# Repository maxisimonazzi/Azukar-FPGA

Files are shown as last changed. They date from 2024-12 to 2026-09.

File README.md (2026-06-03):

<div align="center">
  <h1>AZUKAR Logo  AZUKAR — FPGA Education Board</h1>
  <h1>UTN-FRT - Ingeniería Electrónica</h1>
</div>

[English](#english) | [Español](#español)









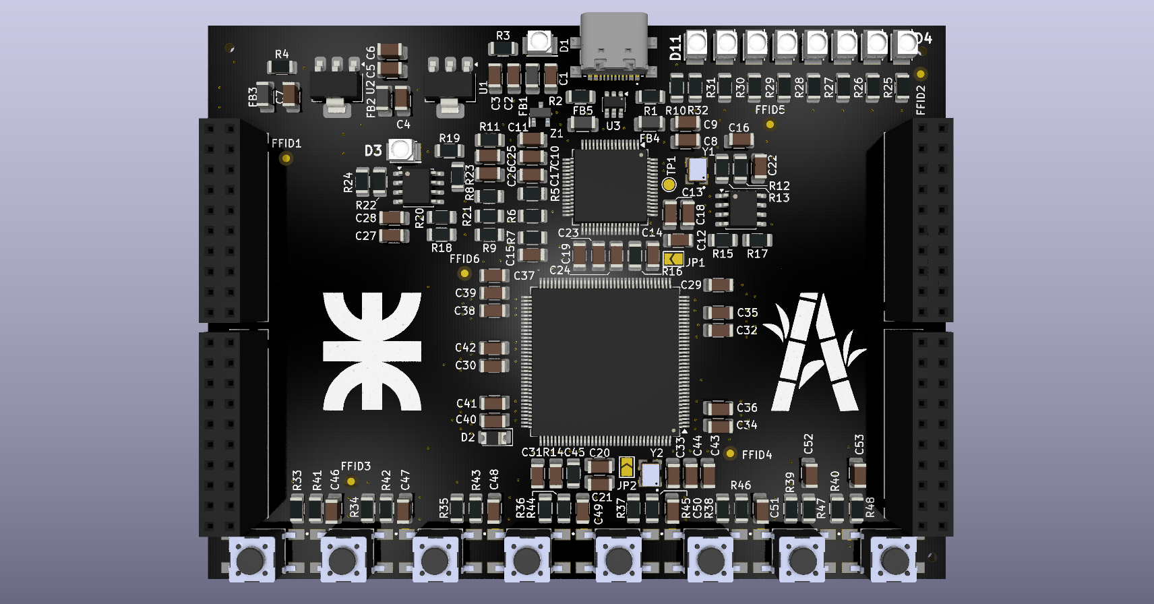
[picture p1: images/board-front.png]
Front Preview

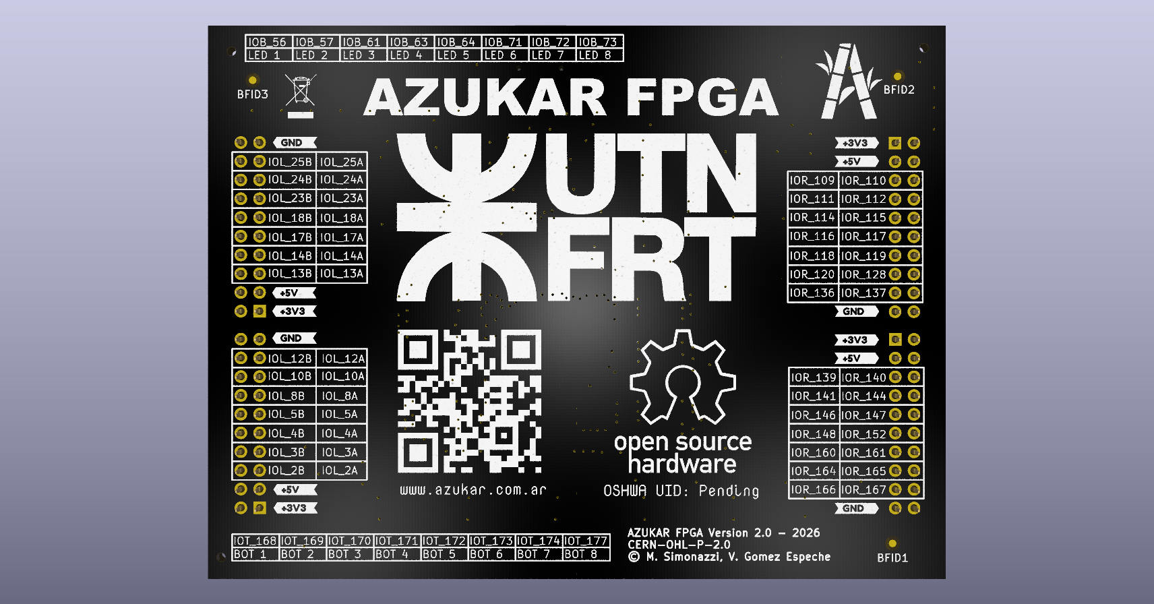
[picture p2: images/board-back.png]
Back Preview


# English

## Overview

**AZUKAR** is an open-source FPGA development board designed for digital design education, laboratory training, and rapid prototyping.
It provides an accessible and reproducible hardware platform that enables students, makers, and engineers to explore HDL design, digital systems architecture, and FPGA-based applications using open toolchains.

The project follows open hardware principles and is optimized for academic environments, hands-on learning, and experimentation.

### Special Considerations

Assembly-first decisions were made to keep the board easy to build in a lab or at home: most parts use common, hand-solderable footprints (e.g., 1206, SOT-233-3, SOIC-8, 3528, SOT-23-6), and all components are placed on the TOP side of the PCB to simplify manual assembly and hot-plate reflow. The only parts that typically require extra precision or a different soldering technique are the FPGA (TQFP-144), the FTDI USB interface (LQFP-64), and the 3225 package crystals. As a trade-off, these assembly-friendly decisions make the routing denser and therefore increase via usage compared to a design that spreads parts across both PCB sides.

## Key Goals

The main idea behind AZUKAR is to make FPGA learning feel approachable and practical, especially in the context of digital design courses and hands-on training. To do that, the board is designed to work well with open-source FPGA toolchains and to keep the hardware design easy to understand, reproduce, and verify.

At the same time, this is meant to be a solid platform for lab work and academic use, not just a one-off prototype. The project is open to contributions and experiments from the community, so people can build on it, adapt it to their needs, and share improvements back.

## Features

AZUKAR is an FPGA-based digital logic platform with fully open hardware design files, created and maintained in KiCad 9. It is intended to work smoothly with open-source synthesis and programming workflows, so the learning experience doesn’t depend on proprietary tools.

From the start, the board is designed with education in mind: the I/O and peripherals are chosen to support typical lab exercises and digital design practice. The overall architecture is modular and extensible, so it can grow with new experiments, add-ons, and future improvements.

## Repository Structure

/docs -> Documentation of the board, pinout, datasheets, etc

/images -> Images

/project -> Kicad project

## Toolchain Compatibility

AZUKAR is designed to fit naturally into open-source FPGA workflows. In practice, that means you can synthesize designs with tools like Yosys, run place-and-route with NextPNR, and program the board using open programming utilities. The goal is to keep the HDL flow as vendor-independent as possible, so the same learning and development approach can be reused across projects.

## Educational Use

This board is intended to be used in real learning environments: university courses, digital electronics labs, and introductory FPGA workshops. It also works well for self-learning and experimentation at home, and it can serve as a practical base for small research prototypes where having an open, reproducible platform is a plus.

## Open Hardware

AZUKAR follows open hardware principles:

- Schematics and PCB files available
- Reproducible fabrication workflow
- Community-driven development

License details are available in the repository.

## Contributing

Contributions are welcome:

- Hardware improvements
- Documentation updates
- Example designs
- Testing and validation
- Educational material

Please open issues or pull requests.

## License

This project is released under an open-source hardware compatible license.  
See the LICENSE file for details.

## Attribution

If you use this project as a reference or as a base for derivative works, the CERN-OHL-P license requires preservation of attribution to the original AZUKAR project.

We strongly encourage including in documentation and repositories:
- A reference to this repository (link and name)
- The original author name
- The license notice

This helps maintain traceability and academic integrity within the open hardware community.

## Disclaimer

This project is an independent hardware design based on publicly available documentation of the Lattice iCE40HX FPGA family.
It is not affiliated with, endorsed by, or supported by Lattice Semiconductor.

---

# Español

## Descripción general

**AZUKAR** es una placa de desarrollo FPGA de código abierto diseñada para la educación en diseño digital, la capacitación de laboratorio y el prototipado rápido.
Proporciona una plataforma de hardware accesible y reproducible que permite a estudiantes, makers e ingenieros explorar el diseño en HDL, la arquitectura de sistemas digitales y aplicaciones basadas en FPGA usando toolchains abiertas.

El proyecto sigue principios de hardware abierto y está optimizado para entornos académicos, aprendizaje práctico y experimentación.

### Consideraciones especiales

Se tomaron decisiones orientadas al montaje para que la placa sea más fácil de construir en laboratorio o en casa: la mayoría de los componentes usan encapsulados comunes y soldables a mano (por ejemplo 1206, SOT-233-3, SOIC-8, 3528, SOT-23-6), y todos los componentes están ubicados en la cara TOP de la PCB para facilitar el armado manual y el soldado por reflow con cama caliente. Los únicos componentes que suelen requerir más precisión o una técnica de soldado diferente son la FPGA (TQFP-144), la interfaz FTDI del puerto USB (LQFP-64) y los cristales en encapsulado 3225. Como contrapartida, estas decisiones orientadas al ensamblado vuelven el ruteo más complejo y, por lo tanto, aumentan la cantidad de vías respecto de un diseño que distribuye componentes en ambas caras de la PCB.

## Objetivos principales

La idea principal de AZUKAR es que aprender FPGA sea más accesible y práctico, especialmente para materias de diseño digital y actividades de laboratorio. Por eso se buscó que la placa pueda trabajar con toolchains de FPGA de código abierto y que el diseño de hardware sea transparente, entendible y fácil de reproducir.

Además, el objetivo es que sirva como una plataforma sólida para uso académico y entrenamiento, no sólo como un prototipo aislado. El proyecto también está pensado para que la comunidad pueda aportar, probar ideas y experimentar, de forma que cualquiera pueda adaptarlo y mejorar lo que ya existe.

## Características

AZUKAR es una plataforma de lógica digital basada en FPGA, con archivos de diseño de hardware totalmente abiertos y desarrollados en KiCad 9. La placa está pensada para integrarse bien con herramientas de síntesis y programación de código abierto, para que el flujo de trabajo sea accesible y fácil de replicar.

También se priorizó el uso educativo: las entradas/salidas y los periféricos apuntan a cubrir prácticas típicas de laboratorio y ejercicios de diseño digital. La arquitectura, además, es modular y extensible, lo que permite sumar ideas, módulos y mejoras con el tiempo.

## Estructura del repositorio

/docs -> Documentación de la placa, pinout, hojas de datos, etc.

/images -> Imágenes

/project -> Proyecto de KiCad

## Compatibilidad con toolchains

AZUKAR está pensada para integrarse de forma natural con flujos de trabajo de FPGA de código abierto. En la práctica, esto incluye poder sintetizar con herramientas como Yosys, hacer place & route con NextPNR y programar la placa con utilidades abiertas. La idea es mantener el flujo de HDL lo más independiente posible del proveedor, para que lo aprendido sea reutilizable y fácil de replicar.

## Uso educativo

Esta placa está pensada para usarse en entornos reales de aprendizaje: cursos universitarios, laboratorios de electrónica digital y talleres introductorios de FPGA. También es muy útil para el autoaprendizaje y la experimentación, y puede servir como base para prototipos de investigación donde suma contar con una plataforma abierta y reproducible.

## Hardware abierto

AZUKAR sigue principios de hardware abierto:

- Esquemáticos y archivos de PCB disponibles
- Flujo de fabricación reproducible
- Desarrollo impulsado por la comunidad

Los detalles de la licencia están disponibles en el repositorio.

## Contribuciones

Las contribuciones son bienvenidas:

- Mejoras de hardware
- Actualizaciones de documentación
- Diseños de ejemplo
- Pruebas y validación
- Material educativo

Por favor, abrir issues o pull requests.

## Licencia

Este proyecto se publica bajo una licencia compatible con hardware abierto y de código abierto.  
Ver el archivo LICENSE para más detalles.

## Atribución

Si utilizás este proyecto como referencia o como base para obras derivadas, la licencia CERN-OHL-P exige que se preserve la atribución al proyecto original AZUKAR.

Se recomienda especialmente incluir en la documentación y repositorios:
- Una referencia a este repositorio (enlace y nombre)
- El nombre del autor original
- El aviso de licencia

Esto ayuda a mantener la trazabilidad y la integridad académica dentro de la comunidad de hardware abierto.

## Descargo de responsabilidad

Este proyecto es un diseño de hardware independiente basado en documentación de acceso público de la familia de FPGA Lattice iCE40HX.
No está afiliado a, avalado por, ni respaldado por Lattice Semiconductor.

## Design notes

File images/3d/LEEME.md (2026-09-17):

# Azukar FPGA — modelo para web

Modelo de presentación generado a partir del proyecto KiCad suministrado. Se mantienen los cuatro conectores laterales, el USB, los pulsadores y los componentes del proyecto. No se modificó el ZIP original.

## Qué archivo usar

- **azukar-web.glb**: 2.178.696 bytes (2,18 MB). Primera opción para reemplazar el modelo en un visor moderno. Texturas incluidas, sin decodificador de geometría adicional. El visor debe soportar KHR_mesh_quantization y EXT_texture_webp.
- **azukar-web-meshopt.glb**: 1.314.468 bytes (1,31 MB). Misma geometría y materiales, comprimidos con Meshopt. Requiere soporte de EXT_meshopt_compression; el decodificador clásico y su licencia están en vendor/.
- **azukar-poster.webp**: 91.058 bytes (91 KB), fondo transparente. Imagen inicial recomendada para la página.
- **azukar-front.webp / azukar-back.webp**: vistas de frente y dorso, de unos 110 y 95 KB.
- **azukar-hero.png / azukar-front.png / azukar-back.png**: renders PNG transparentes de mayor calidad.
- **azukar-editable.blend**: escena editable de Blender 5.0.1 con texturas empaquetadas, cámara e iluminación. No necesitás Blender para mostrar los GLB en la web.

Las dimensiones del PCB se mantienen en 100 × 75 × 1,6 mm. glTF utiliza metros. La cara de componentes apunta hacia +Y en el GLB. La escena Blender conserva la cara de componentes hacia +Z.

## Qué se optimizó

La exportación completa de referencia del mismo proyecto, con pistas, pads, zonas, máscara y serigrafía como geometría, medía 23.832.564 bytes. Contenía 463.670 triángulos y 29.004 primitivas. No es una medición del antiguo archivo del sitio.

Los dos GLB finales tienen 59.827 triángulos y 20 primitivas: aproximadamente 87 % menos triángulos y 99,93 % menos primitivas. Las primitivas son lotes de geometría/material, no una medición literal de todas las llamadas de dibujo del navegador: sombras y otras pasadas pueden sumar llamadas.

- Las 200 vías pequeñas se representan mediante textura/relieve superficial, sin cilindros ni perforaciones internas.
- Se conservan las 85 perforaciones de las huellas; se simplifica su contorno.
- Pistas, máscara, pads, logos y serigrafía se obtienen de las capas reales del PCB, no de una imagen inventada.
- Se simplifican los componentes y se agrupa la geometría por material.
- Se añaden materiales de plástico, cerámica y metal. El color, la rugosidad y el relieve son una aproximación visual basada en las referencias; no una medición física.
- El color de cada cara se guarda a 2048 × 1536; los mapas de relieve y propiedades del material, a 1024 × 768. Se comprimen en WebP.

No es un modelo para fabricación, análisis mecánico preciso o inspección de vías internas. No se inventaron marcas láser ni textos de los chips ausentes en los modelos fuente. La apariencia final también depende de la iluminación y exposición del visor.

## Cómo evitar que frene la página

La compresión del archivo por sí sola no elimina el coste de cargar el motor 3D, preparar materiales y subir datos a la GPU.

1. Mostrar azukar-poster.webp como imagen normal al abrir la página.
2. Cargar el código del visor y asignar el GLB solamente al pulsar «Explorar en 3D».
3. Mantener la imagen mientras se prepara el modelo; conservarla también si WebGL o la carga fallan.
4. No precargar el GLB ni importar el motor 3D desde el módulo inicial.
5. Evitar el giro automático permanente. En visores propios, renderizar cuando cambia la vista; limitar la resolución en pantallas de alta densidad.

El botón de activación protege la carga inicial. Al activar el 3D todavía puede haber trabajo en el hilo principal: no es una garantía de cero pausas en todos los dispositivos. La descarga asíncrona, un setTimeout o requestIdleCallback por sí solos no llevan todo el render a un worker.

Para model-viewer 4.3.1, cargar la biblioteca con import() dentro del manejador del botón y crear el elemento después. Si se usa la variante Meshopt, antes de crear el elemento:

```js
customElements.get('model-viewer').meshoptDecoderLocation =
  '/ruta-a-los-assets/vendor/meshopt_decoder.js';
```

Esa propiedad requiere el script clásico incluido, no meshopt_decoder.module.js. Para un visor Three.js propio, configurar GLTFLoader.setMeshoptDecoder() con el módulo MeshoptDecoder correspondiente. Con azukar-web.glb no hace falta esta configuración.

Referencias oficiales: [carga en model-viewer](https://modelviewer.dev/examples/loading/), [API de model-viewer](https://modelviewer.dev/docs/index.html), [gltfpack](https://github.com/zeux/meshoptimizer/blob/v1.2/gltf/README.md).

## Verificación y alcance

Los GLB cargaron sin errores JavaScript en Edge/Chromium con model-viewer 4.3.1. Se revisaron las vistas de frente, dorso y perspectiva. La prueba local comprobó que no se solicita el GLB ni la biblioteca del visor antes de pulsar el botón.

El validador glTF no encontró errores ni advertencias. Para Meshopt, el validador declara que no inspecciona internamente la extensión comprimida; su carga se comprobó además en el navegador. Las pruebas funcionales con CPU limitada a 4× no sustituyen una medición en teléfonos reales y con la red del sitio.

La integración en la página existente queda pendiente: no se encontró el código del sitio en la carpeta de trabajo original durante esta tarea. Este paquete no cambia ningún despliegue.

Se usaron KiCad 10.0, Blender 5.0.1 y gltfpack 1.2. No se utilizó IA generativa para reconstruir componentes, logos o circuitos. Los derechos y licencias del diseño y de los modelos fuente se mantienen; el procesamiento no los cambia.

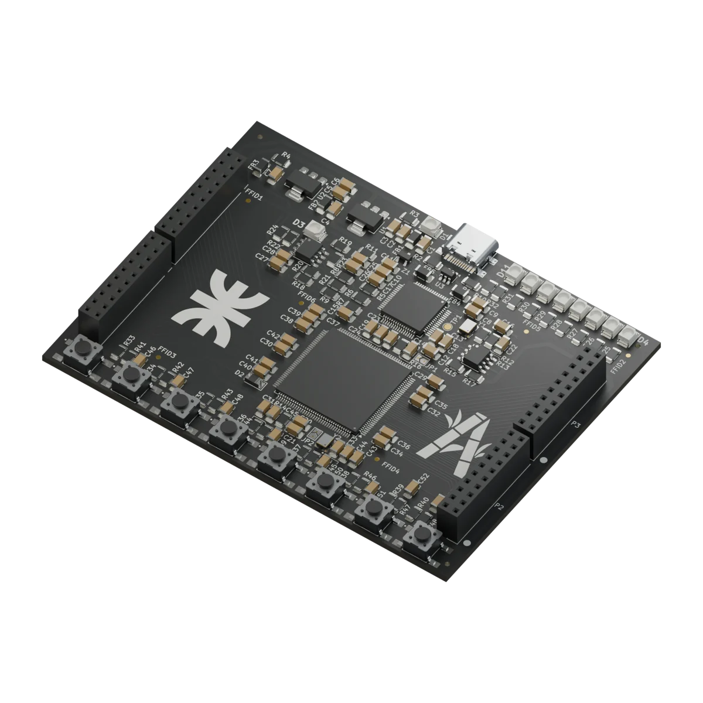
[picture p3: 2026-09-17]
images/3d/azukar-poster.webp

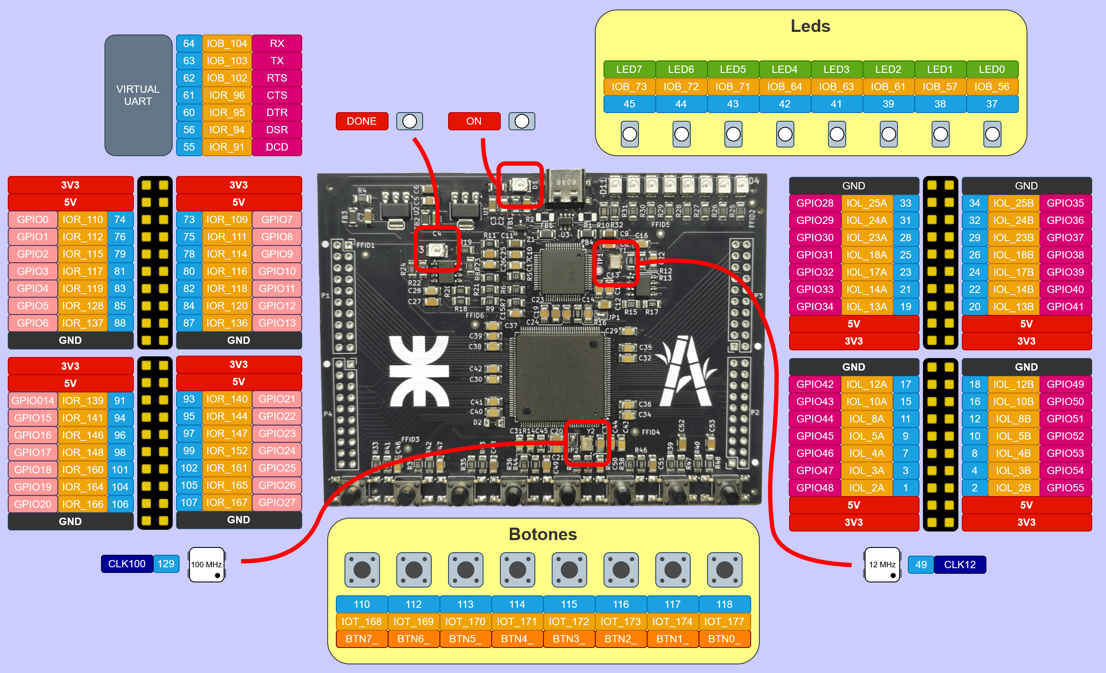
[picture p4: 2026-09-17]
docs/pinout/Pinout Azukar v2.png

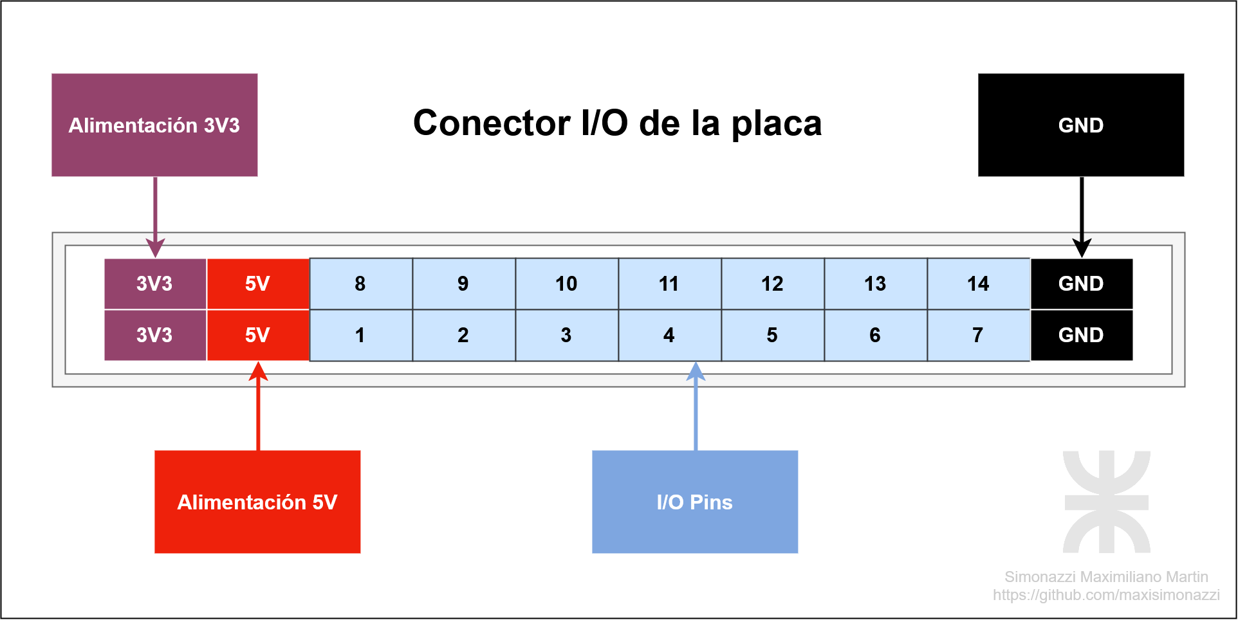
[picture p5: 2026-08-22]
docs/pinout/IO-connector.png

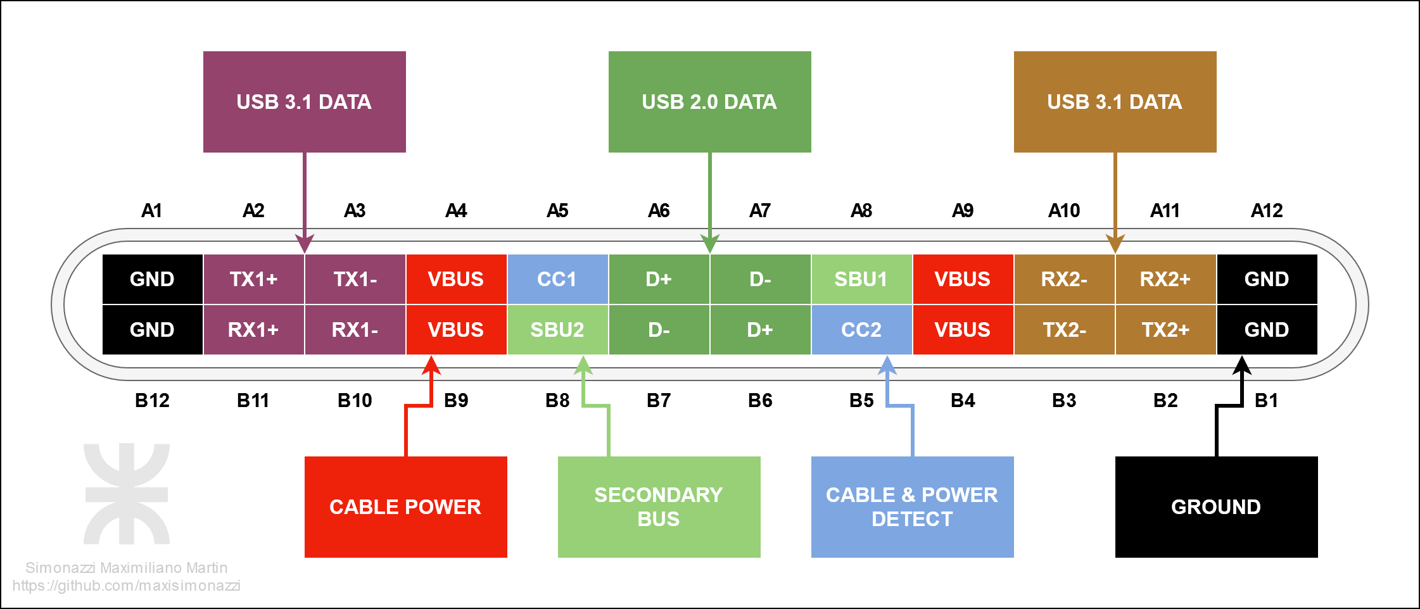
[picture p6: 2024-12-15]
docs/pinout/usb_c_pinout.png

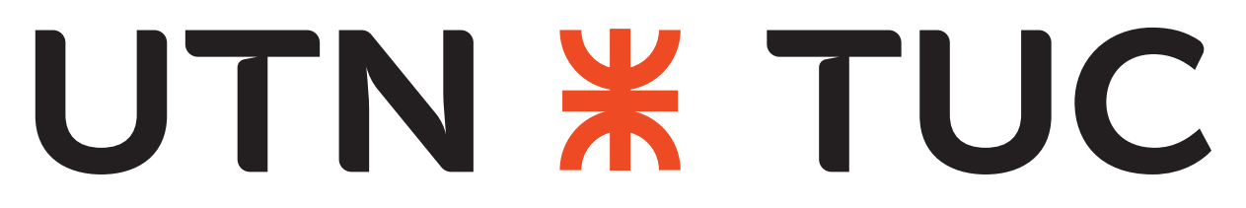
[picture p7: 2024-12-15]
images/utn_tuc_nuevo.png

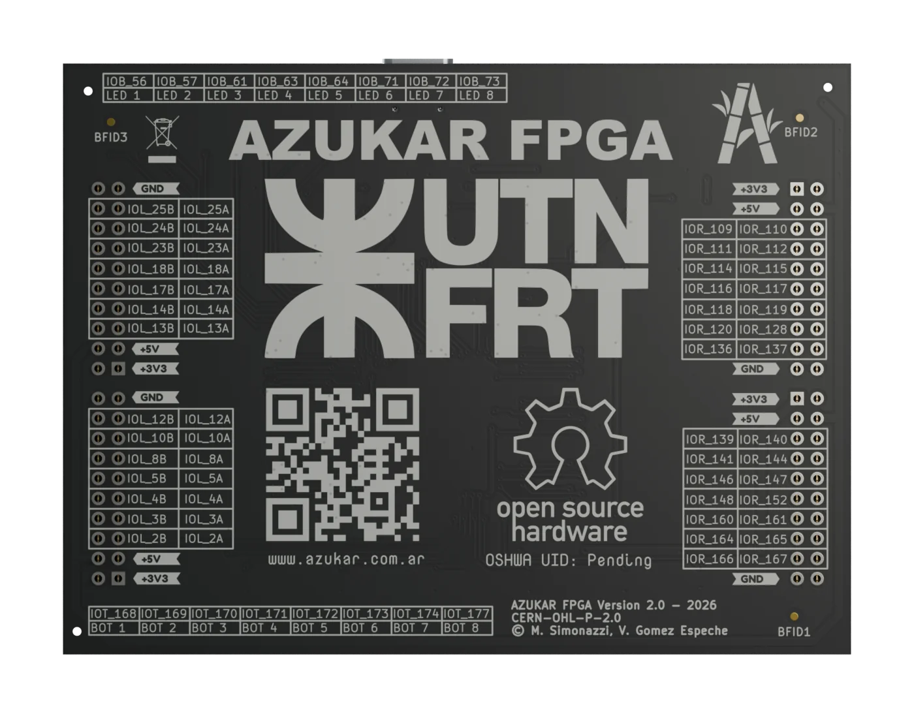
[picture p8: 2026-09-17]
images/3d/azukar-back.webp

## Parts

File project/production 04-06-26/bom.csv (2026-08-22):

Designator | Footprint | Quantity | Value | LCSC Part #
BFID1, BFID2, BFID3, FFID1, FFID2, FFID3, FFID4, FFID5, FFID6 | Fiducial_1mm_Mask2mm | 9 | Fiducial
C1, C25, C27 | 1206 | 3 | 10n
C10, C13, C14, C15, C16, C17, C18, C19, C2, C21, C22, C24, C29, C30, C31, C32, C33, C35, C36, C38, C39, C41, C42, C44, C45, C5, C8 | 1206 | 27 | 100n
C11, C9 | 1206 | 2 | 4u7
C12 | 1206 | 1 | 3u3
C20, C23, C3, C4, C46, C47, C48, C49, C50, C51, C52, C53, C6, C7 | 1206 | 14 | 10u
C26, C28, C34, C37, C40, C43 | 1206 | 6 | 1u
D1, D3 | LEDM3528X210N | 2 | LED Red
D10, D11, D4, D5, D6, D7, D8, D9 | LEDM3528X210N | 8 | LED Green
D2 | 1206 | 1 | D_Schottky
FB1, FB2, FB3, FB4, FB5 | 1206 | 5 | FerriteBead_Small
J1 | GSB1C41110SSHR | 1 | USB_C_Receptacle_USB2.0_16P
P1, P2, P3, P4 | PinSocket_2x10_P2.54mm_Vertical | 4 | Conector 2x10
R1, R2 | 1206 | 2 | 5k1
R10 | 1206 | 1 | 12k
R11, R24, R3 | 1206 | 3 | 1k
R12, R13, R17, R18, R19, R20, R41, R42, R43, R44, R45, R46, R47, R48 | 1206 | 14 | 10k
R14, R16 | 1206 | 2 | 100
R15 | 1206 | 1 | 2k2
R21, R22, R23, R25, R26, R27, R28, R29, R30, R31, R32, R33, R34, R35, R36, R37, R38, R39, R40, R5, R6, R7, R8, R9 | 1206 | 24 | 220
R4 | 1206 | 1 | 120
SW1, SW2, SW3, SW4, SW5, SW6, SW7, SW8 | SW_TS04-66-75-BK-100-SMT | 8 | SW_Push
TP1 | TestPoint_Pad_D1.5mm | 1 | TP_PWR_EN
U1 | SOT-223-3_TabPin2 | 1 | TLV76133DCYR
U2 | SOT-223-3_TabPin2 | 1 | TLV76112DCYR
U3 | SOT-23-6 | 1 | USBLC6-2SC6
U4 | LQFP-64_10x10mm_P0.5mm | 1 | FT2232HL
U5 | SOIC-8_3.9x4.9mm_P1.27mm | 1 | M93C66
U6 | TQFP-144_20x20mm_P0.5mm | 1 | ICE40HX4K-TQ144
U7 | SOIC-8_3.9x4.9mm_P1.27mm | 1 | W25X40CLSN
Y1 | OSC_ECS-3225MV-120-CN-TR | 1 | ECS-3225MV-120-CN-TR
Y2 | OSC_ECS-3225MV-120-CN-TR | 1 | ECS-3225MVQ-1000-CN-TR
Z1 | SOT96P237X111-3N | 1 | MMBZ5231BLT3G

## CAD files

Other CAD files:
images/3d/azukar-editable.blend

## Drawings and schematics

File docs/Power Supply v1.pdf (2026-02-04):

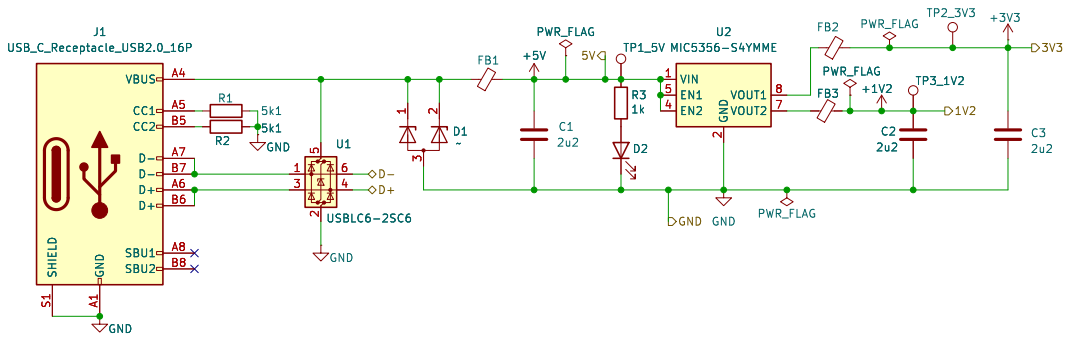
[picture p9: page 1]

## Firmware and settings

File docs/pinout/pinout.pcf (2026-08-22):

# -----------------------------------------------------------------------------
#- Azukar v2 constraint file (.pcf)
#- Oct - 2025
#- CERN Open Hardware Licence Version 2 - Permissive
#- Repo: https://github.com/maxisimonazzi/Azukar-FPGA - https://www.azukar.com.ar
#- Pinout: https://github.com/maxisimonazzi/Azukar-FPGA/blob/main/docs/pinout/Pinout%20Azukar%20v2.png
# -----------------------------------------------------------------------------

# ------------ Buttons (active low)
set_io -nowarn BTN0_ 118  # input
set_io -nowarn BTN1_ 117  # input
set_io -nowarn BTN2_ 116  # input
set_io -nowarn BTN3_ 115  # input
set_io -nowarn BTN4_ 114  # input
set_io -nowarn BTN5_ 113  # input
set_io -nowarn BTN6_ 112  # input
set_io -nowarn BTN7_ 110  # input

# ------------ User LEDs
set_io -nowarn LED0 37  #-- output
set_io -nowarn LED1 38  #-- output 
set_io -nowarn LED2 39  #-- output
set_io -nowarn LED3 41  #-- output 
set_io -nowarn LED4 42  #-- output 
set_io -nowarn LED5 43  #-- output
set_io -nowarn LED6 44  #-- output 
set_io -nowarn LED7 45  #-- output

# ------------ SYSTEM CLOCK
set_io -nowarn CLK12 49    # input
set_io -nowarn CLK100 129  # input

# ------------ FTDI (Virtual Serial port)
set_io -nowarn RX  64  # input
set_io -nowarn TX  63  # output
set_io -nowarn RTS 62  # input
set_io -nowarn CTS 61  # output
set_io -nowarn DTR 60  # input
set_io -nowarn DSR 56  # output
set_io -nowarn DCD 55  # output

# ------------ GPIO Bank 1
set_io -nowarn GPIO0 74  # input/output
set_io -nowarn GPIO1 76  # input/output
set_io -nowarn GPIO2 79  # input/output
set_io -nowarn GPIO3 81  # input/output
set_io -nowarn GPIO4 83  # input/output
set_io -nowarn GPIO5 85  # input/output
set_io -nowarn GPIO6 88  # input/output
set_io -nowarn GPIO7 73  # input/output
set_io -nowarn GPIO8 75  # input/output
set_io -nowarn GPIO9 78  # input/output
set_io -nowarn GPIO10 80  # input/output
set_io -nowarn GPIO11 82  # input/output
set_io -nowarn GPIO12 84  # input/output
set_io -nowarn GPIO13 87  # input/output

# ------------ GPIO Bank 2
set_io -nowarn GPIO14 91  # input/output
set_io -nowarn GPIO15 94  # input/output
set_io -nowarn GPIO16 96  # input/output
set_io -nowarn GPIO17 98  # input/output
set_io -nowarn GPIO18 101  # input/output
set_io -nowarn GPIO19 104  # input/output
set_io -nowarn GPIO20 106  # input/output
set_io -nowarn GPIO21 93  # input/output
set_io -nowarn GPIO22 95  # input/output
set_io -nowarn GPIO23 97  # input/output
set_io -nowarn GPIO24 99  # input/output
set_io -nowarn GPIO25 102  # input/output
set_io -nowarn GPIO26 105  # input/output
set_io -nowarn GPIO27 107  # input/output

# ------------ GPIO Bank 3
set_io -nowarn GPIO28 33  # input/output
set_io -nowarn GPIO29 31  # input/output
set_io -nowarn GPIO30 28  # input/output
set_io -nowarn GPIO31 25  # input/output
set_io -nowarn GPIO32 23  # input/output
set_io -nowarn GPIO33 21  # input/output
set_io -nowarn GPIO34 19  # input/output
set_io -nowarn GPIO35 34  # input/output
set_io -nowarn GPIO36 32  # input/output
set_io -nowarn GPIO37 29  # input/output
set_io -nowarn GPIO38 26  # input/output
set_io -nowarn GPIO39 24  # input/output
set_io -nowarn GPIO40 22  # input/output
set_io -nowarn GPIO41 20  # input/output

# ------------ GPIO Bank 4
set_io -nowarn GPIO42 17  # input/output
set_io -nowarn GPIO43 15  # input/output
set_io -nowarn GPIO44 11  # input/output
set_io -nowarn GPIO45 9   # input/output
set_io -nowarn GPIO46 7   # input/output
set_io -nowarn GPIO47 3   # input/output
set_io -nowarn GPIO48 1   # input/output
set_io -nowarn GPIO49 18  # input/output
set_io -nowarn GPIO50 16  # input/output
set_io -nowarn GPIO51 12  # input/output
set_io -nowarn GPIO52 10  # input/output
set_io -nowarn GPIO53 8   # input/output
set_io -nowarn GPIO54 4   # input/output
set_io -nowarn GPIO55 2   # input/output

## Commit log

2024-12-11 Commit inicial
    [fpga-utn.kicad_pcb, fpga-utn.kicad_sch, power_supply.kicad_sch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]
2024-12-15 Regulador V1 finalizado
    [fpga-utn.kicad_sch, power_supply.kicad_sch]
2024-12-28 Sección de FTDI casi terminada. Definir oscilador y nombres de puertos
    [FTDI.kicad_sch, fpga-utn.kicad_sch, power_supply.kicad_sch]
2024-12-29 Added readme.md lost in last commit
    [untitled.kicad_sch]
2025-07-07 Guardado previo, FTDI casi listo
    [FTDI.kicad_sch, fpga-utn.kicad_sch, fpga.kicad_sch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]
2025-07-07 Corrigiendo errores de conexiones en la memorias
    [fpga-utn.kicad_sch, memorias.kicad_sch]
2025-07-08 Inicio de la PCB y conexion del PLL
    [FTDI.kicad_sch, fpga-utn.kicad_sch, fpga.kicad_sch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]
2025-10-01 Eliminación de archivos de respaldo y correcciones en la biblioteca de componentes. Se eliminaron archivos de autosave, archivos de esquemas y modelos 3D no utilizados, así como modificaciones en las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
    [FTDI.kicad_sch, fpga-utn.kicad_pcb, fpga-utn.kicad_sch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]
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2025-10-01 Agregado TODO para futuro. Agregado clock de 12 MHz a la FPGA. Agregado pinout de conector 2x10.
    [FTDI.kicad_sch, fpga-utn.kicad_sch, perifericos.kicad_sch]
2025-10-01 - Included properties such as Reference, Value, Footprint, and various manufacturer details. - Defined 20 pins with appropriate names and attributes for the symbol. - Ensured compatibility with KiCad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
    [FTDI.kicad_sch, fpga-utn.kicad_pcb, memorias_pll.kicad_sch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]
2025-10-01 Agregados footprints de todos los componentes
    [FTDI.kicad_sch, fpga-utn.kicad_pcb, memorias_pll.kicad_sch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]
2025-10-02 PCB etapa de potencia y comunicacion lista
    [FTDI.kicad_sch, fpga-utn.kicad_pcb, perifericos.kicad_sch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]
2025-10-02 Componentes colocados, version 1
    [fpga-utn.kicad_pcb]
2025-10-11 Version 1 pcb, sin finalizar
    [FTDI.kicad_sch, fpga-utn.kicad_pcb, perifericos.kicad_sch]
2025-10-12 Ruteo critico finalizado
    [FTDI.kicad_sch, fpga-utn.kicad_pcb, fpga-utn.kicad_sch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]
2025-11-28 Ruteado completo en V1
    [fpga-utn-B_Adhesive.gbr, fpga-utn-B_Cu.gbr, fpga-utn-B_Mask.gbr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]
2026-01-08 DRC checkeado
    [fpga-utn.kicad_pcb]
2026-01-08 DRC checkeado y fiduciales agregados
    [fpga-utn.kicad_pcb, fpga-utn.kicad_sch]
2026-01-26 pcbv1 silkscreen front
    [fpga-utn-B_Adhesive.gbr, fpga-utn-B_Cu.gbr, fpga-utn-B_Mask.gbr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]
2026-01-26 pcbv1 silkscreen back connectors
    [fpga-utn.kicad_pcb]
2026-01-26 Back silkscreen finished
    [fpga-utn.kicad_pcb]
2026-01-29 pcbv1 version finalizada, correcciones de pistas, agregado logo azukar, etc
    [fpga-utn.kicad_pcb]
2026-01-29 Correccion en nombre y logo
    [fpga-utn.kicad_pcb]
2026-01-31 Agregado de datasheets, cambio de regulador zener, ajuste de posicion de regulador, modelo 3d de oscilador
    [FTDI.kicad_sch, fpga-utn.kicad_pcb, fpga-utn.kicad_sch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]
2026-01-31 Correcion de errores ERC y DRC, avisos ERC y DRC, correccion de huellas, silksreens pisando soldermask, etc
    [fpga-utn.kicad_pcb, perifericos.kicad_sch]
2026-02-01 Pistas, pads, soldermask y silkscreen corregidas para pasar analisis DMF de jlcpcb.
    [fpga-utn.kicad_pcb, fpga-utn.kicad_sch, memorias_pll.kicad_sch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]
2026-02-02 pista de linea 3v3 ampliada
    [fpga-utn.kicad_pcb]
2026-02-04 Correciones de pistas varias, sacando una pista entre pads de la eeprom, ordenamiento de algunas vias, cambio de cristal de 12mhz al lado del ftdi, etc
    [fpga-utn.kicad_pcb, perifericos.kicad_sch]
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2026-02-04 actualizacion readme
    [power_supply.kicad_sch]
2026-02-04 Agregada licencia CERN-OHL-P-2.0
    [fpga-utn.kicad_pcb, fpga-utn.kicad_sch, licencia.kicad_sch]
2026-02-04 cambio a nombre final, agregado de licencia en esquematico y etiqueta
    [FTDI.kicad_sch, azukar-fpga.kicad_pcb, azukar-fpga.kicad_sch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]
2026-02-05 Revision de traza de 3V3 que pasaba por debajo del cristal de 100, movido capacitor de 100 nF cerca del cristal de 12.
    [azukar-fpga.kicad_pcb]
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2026-02-06 Eliminar mensaje de error - Issue #8. Mejora en algunas trazas del PCB, eliminacion de algunas vias ordenando mejor los componentes.
    [azukar-fpga.kicad_pcb, azukar-fpga.kicad_sch, licencia.kicad_sch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]
2026-02-07 Mejorado el ruteo, eliminadas algunas vias, anillo de 3V3 cerrado
    [azukar-fpga.kicad_pcb]
2026-02-15 pequeño rework a la pcb
    [azukar-fpga.kicad_pcb, licencia.kicad_sch]
2026-03-08 Version 2 de pcb completa, falta revisar silkscreen y ajustes menores
    [FTDI.kicad_sch, azukar-fpga.kicad_pcb, azukar-fpga.kicad_sch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]
2026-03-08 actualizados anchos de pistas de potencia
    [azukar-fpga.kicad_pcb]
2026-03-09 Deleting old files
    [azukar-fpga.kicad_pcb]
2026-03-10 Reordenadas las resistencias y capacitores de los botones y separaciones
    [azukar-fpga.kicad_pcb, azukar-fpga.kicad_sch]
2026-03-11 Corregida serigrafia frontal, modificada serigrafia trasera
    [azukar-fpga.kicad_pcb]
2026-04-07 Mejoras en pcb
    [FTDI.kicad_sch, azukar-fpga.kicad_pcb]
2026-05-29 cambios en disposicion de esquematico
    [FTDI.kicad_sch, azukar-fpga.kicad_sch, licencia.kicad_sch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]
2026-06-01 Corregidos footprints, generada nuevas capturas, cambiado regulador por TLV761
    [FTDI.kicad_sch, azukar-fpga.kicad_pcb, power_supply.kicad_sch]
2026-06-01 Agregado datasheet faltante y completado cuadro de BOM con sus links
    [memorias_pll.kicad_sch, perifericos.kicad_sch, power_supply.kicad_sch]
2026-08-22 Archivos a prod en 2026, pinout placa, incoming datasheets
    [azukar-fpga.kicad_pcb, bom.csv, designators.csv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]
2026-09-13 nuevo render y placa en glb
    [azukar-editable.blend]
